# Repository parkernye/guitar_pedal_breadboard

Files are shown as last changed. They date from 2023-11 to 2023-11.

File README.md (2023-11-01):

# guitar_pedal_breadboard
Prototype Board for Guitar Pedals

I wanted a simple PCB that I could place two breadboards on to help prototype my guitar pedals. 
It features multiple supply voltages, an input and output jack, and spots to plug in potentiometers of different values. 
Inspiration taken from the PedalPCB protoboard.



Future Modifications
- Swap DC jack polarity to match guitar pedal standards
- Add 'stereo' capabilities

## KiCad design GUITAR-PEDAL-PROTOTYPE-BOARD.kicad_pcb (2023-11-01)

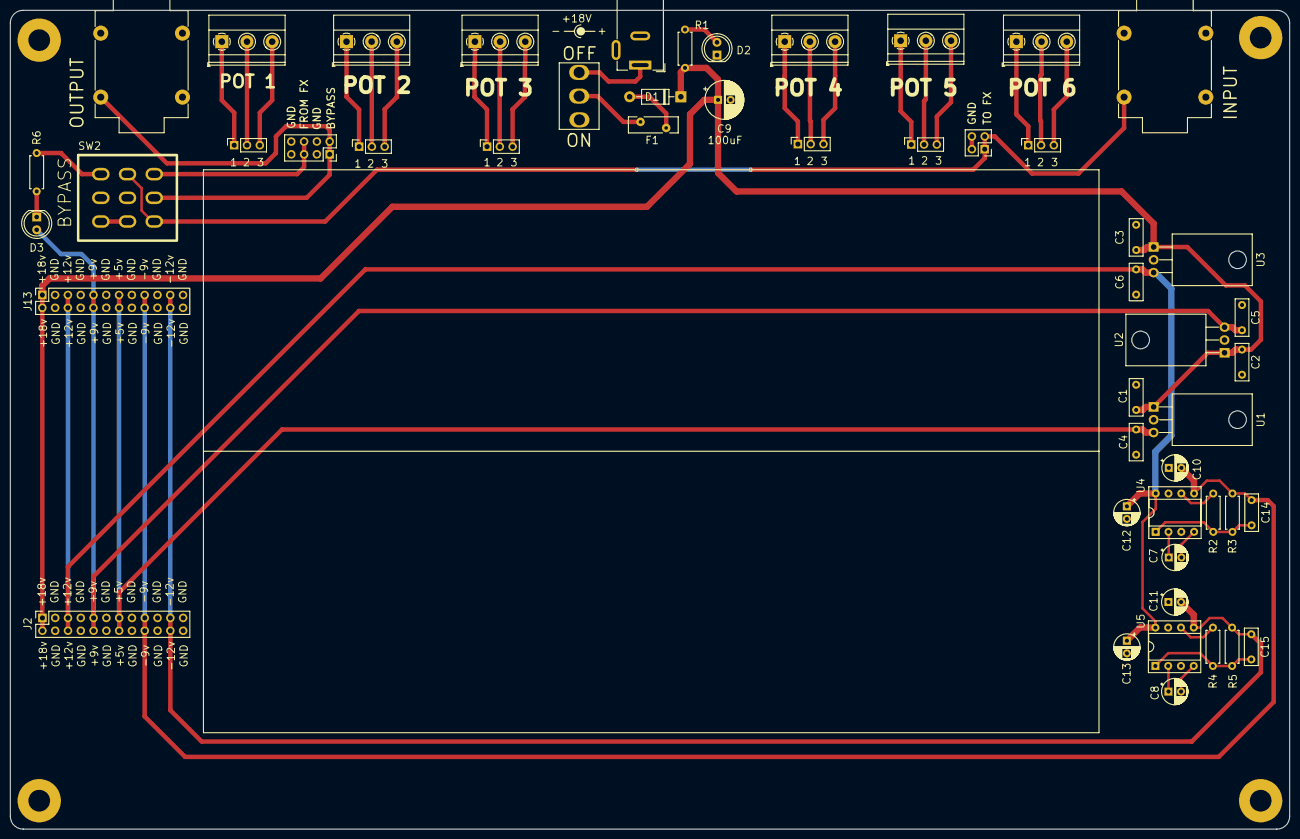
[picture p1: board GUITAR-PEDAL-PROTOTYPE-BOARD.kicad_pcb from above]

Board: 2 copper layers, 254.0 x 162.6 mm, 51 parts (0 on the bottom side), 43 nets.

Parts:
C1, C2, C3: .33uF; C_Rect_L7.2mm_W2.5mm_P5.00mm_FKS2_FKP2_MKS2_MKP2
C4, C5, C6, C14, C15: .1uF; C_Rect_L7.2mm_W2.5mm_P5.00mm_FKS2_FKP2_MKS2_MKP2
C7, C8: 10uF; CP_Radial_D5.0mm_P2.50mm
C9: 100uF; CP_Radial_D7.5mm_P2.50mm
C10, C11, C12, C13: 2.2uF; CP_Radial_D5.0mm_P2.50mm
D1: 1N5817; D_DO-41_SOD81_P10.16mm_Horizontal
D2, D3: LED; LED_D5.0mm
F1: Polyfuse; Fuse_Bourns_MF-RHT100
J1: Barrel_Jack_Switch; BarrelJack_Wuerth_6941xx301002
J2, J13: Conn_02x12_Odd_Even; PinSocket_2x12_P2.54mm_Vertical
J3, J5: AudioJack2_Dual_Switch; Jack_6.35mm_Neutrik_NMJ4HFD2_Horizontal
J4: Conn_02x02_Odd_Even; PinSocket_2x02_P2.54mm_Vertical
J6: Conn_02x04_Odd_Even; PinSocket_2x04_P2.54mm_Vertical
J7, J8, J9, J10, J11, J12: Conn_01x03; TerminalBlock_Phoenix_MKDS-1,5-3_1x03_P5.00mm_Horizontal
J15, J16, J17, J18, J19, J20: Conn_01x03; PinSocket_1x03_P2.54mm_Vertical
R1, R6: 4k7; R_Axial_DIN0207_L6.3mm_D2.5mm_P7.62mm_Horizontal
R2, R4: 20k; R_Axial_DIN0207_L6.3mm_D2.5mm_P7.62mm_Horizontal
R3: 180k; R_Axial_DIN0207_L6.3mm_D2.5mm_P7.62mm_Horizontal
R5: 220k; R_Axial_DIN0207_L6.3mm_D2.5mm_P7.62mm_Horizontal
SW1: SW_SPST; THT-SWITCH-SPST
SW2: SW_Stomp_3PDT_Tayda
U1: L7805; TO-220-3_Horizontal_TabDown
U2: L7809; TO-220-3_Horizontal_TabDown
U3: L7812; TO-220-3_Horizontal_TabDown
U4, U5: LT1054; DIP-8_W7.62mm_Socket

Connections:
+4V: C1.1, C2.1, C3.1, C9.1, D1.1 (K), J2.1, J2.2, J13.1, J13.2, R1.1, U1.1 (IN), U2.1 (IN), U3.1 (IN)
+5V: C4.1, J2.13, J2.14, J13.13, J13.14, U1.3 (OUT)
+9V: C5.1, D3.2 (A), J2.9, J2.10, J13.9, J13.10, U2.3 (OUT)
+12V: C6.1, C12.1, C13.1, J2.5, J2.6, J13.5, J13.6, U3.3 (OUT), U4.8 (V+), U5.8 (V+)
-9V: C10.2, C14.1, J2.17, J2.18, J13.17, J13.18, R3.1, U4.5 (-VOUT)
-12V: C11.2, C15.1, J2.21, J2.22, J13.21, J13.22, R5.1, U5.5 (-VOUT)
BREADBOARD_OUT: J6.5, J6.6, SW2.7 (A)
INPUT_SLEEVE: C1.2, C2.2, C3.2, C4.2, C5.2, C6.2, C9.2, C10.1, C11.1, C12.2, C13.2, D2.1 (K), J1.2, J1.3, J2.3, J2.4, J2.7, J2.8, J2.11, J2.12, J2.15, J2.16, J2.19, J2.20, J2.23, J2.24, J3.S, J4.3, J4.4, J5.S, J6.3, J6.4, J6.7, J6.8, J13.3, J13.4, J13.7, J13.8, J13.11, J13.12, J13.15, J13.16, J13.19, J13.20, J13.23, J13.24, SW2.2 (B), U1.2 (GND), U2.2 (GND), U3.2 (GND), U4.3 (GND), U5.3 (GND)
INPUT_TIP: J3.T, J4.1, J4.2, SW2.4 (A), SW2.9 (C)
unnamed: C7.1, U4.2 (CAP+)
unnamed: C7.2, U4.4 (CAP-)
unnamed: C8.1, U5.2 (CAP+)
unnamed: C8.2, U5.4 (CAP-)
unnamed: C14.2, R2.2, R3.2, U4.1 (FB/SHDN)
unnamed: C15.2, R4.2, R5.2, U5.1 (FB/SHDN)
unnamed: D1.2 (A), F1.2
unnamed: D2.2 (A), R1.2
unnamed: D3.1 (K), R6.2
unnamed: F1.1, SW1.2 (B)
unnamed: J1.1, SW1.1 (A)
unnamed: J10.1, J18.1
unnamed: J10.2, J18.2
unnamed: J10.3, J18.3
unnamed: J11.1, J19.1
unnamed: J11.2, J19.2
unnamed: J11.3, J19.3
unnamed: J12.1, J20.1
unnamed: J12.2, J20.2
unnamed: J12.3, J20.3
unnamed: J7.1, J15.1
unnamed: J7.2, J15.2
unnamed: J7.3, J15.3
unnamed: J8.1, J16.1
unnamed: J8.2, J16.2
unnamed: J8.3, J16.3
unnamed: J9.1, J17.1
unnamed: J9.2, J17.2
unnamed: J9.3, J17.3
unnamed: R2.1, U4.6 (VREF)
unnamed: R4.1, U5.6 (VREF)
unnamed: R6.1, SW2.1 (A)
unnamed: SW2.3 (C), SW2.6 (C)
OUTPUT_TIP: J5.T, J6.1, J6.2, SW2.8 (B)
